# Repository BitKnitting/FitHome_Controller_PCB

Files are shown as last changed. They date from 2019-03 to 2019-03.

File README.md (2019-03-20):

# Tisham_PCB_Feather
The goal of this PCB is to supply a Feather to provide the CPU and networking.
# SPI
The meter and CPU talk to each other using SPI.  I just can't map SPI between CPUs and their slaves enough times not to get confused by the differing nomenclatures.  Tisham's labeling of SPI used the SI/SO nomenclature on the slave (the meters) and MOSI/MISO on the master (the CPU).  This maps to:  
SPI mapping  

## CS Pins

I plan to support Feather LoRa and Huzzah.  This way, I can do either RFM95 or wifi.  
### Huzzah
Previously, I used pins 0 and 15 for the two CS pins.  Here is the pinout diagram for the Huzzah:  
Huzzah pinout diagram  

The "0" and "15" refer to how the IDE (Arduino, CP) identify the pin.  The "physical pin" for 0 is 12 and for 15 is 10.  Because all of this confuses me quickly, I can best find these by noting:  
* one CS pin - I'll id as CS 0 -  is 5 pins up on the right.  This is pin 0(IDE)/12(physical).
* one CS pin is 6 pins up on the right.  This is pin 15(IDE)/10(physical).
__Tested both.  I could set pin values to HIGH (3.3) and LOW (0.0).__  
### LoRa
Here is the pinout diagram for the LoRa:  
LoRa pinout diagram

* The pin 5 pins up on the right is 9 (IDE) / 12 (physical)   Hopefully this can also be CS 0 
* The pin 6 pins up on the right is 10 (IDE) / 27 (physical). 
__Tested both.  I could set pin values to HIGH (3.3) and LOW (0.0).__
## 3V3 In

# Circuit Python
I keep getting different Feathers that need CP installed.  Steps to install:  
* [Download the right version of CP from here](https://github.com/adafruit/circuitpython/releases/latest).  
## Huzzah
I'm conflicted if the Huzzah if Adafruit has dropped support for the Huzzah.  The .bin is included in the latest releases.  So I'm using that.
You'll need the [ampy](https://learn.adafruit.com/micropython-basics-load-files-and-run-code/install-ampy) and [esptool](https://pypi.org/project/esptool/) tools installed.
* First thing to do is erase the flash on the ESP826.  I like to start by naming the port, then erasing.
```
$ export PORT=/dev/tty.SLAB_USBtoUART
$ esptool.py -p $PORT erase_flash
```
* Jumper GPIO0 and GND so the ESP826 is in boot mode.
* Write the bin you downloaded (I renamed my cphuzzah.bin)  
```
esptool.py -p /dev/cu.SLAB_USBtoUART write_flash --flash_size=detect 0 cphuzzah.bin
```
* Remove the jumper wire and hit the restart button.

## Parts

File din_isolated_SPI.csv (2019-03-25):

Reference | Value | Footprint | Datasheet | Availability | Description | MP | PN | Package | Price | manf# | DNP
U1 | SI8661AB-B-IS1 | Housings_SOIC:SOIC-16_3.9x9.9mm_Pitch1.27mm | Silicon Labs | Warning | General Purpose tal Isolator 2500Vrms 6 Channel 1Mbps 35kV/µs CMTI 16-SOIC (0.154 , 3.90mm Width) | SI8661AB-B-IS1 | SI8661AB-B-IS1 | SOIC-16 Silicon Labs | 2.12 USD | SI8661AB-B-IS1
J1 | CONN_01X10 | Connectors_Molex:Molex_MicroLatch-53253-1070_10x2.00mm_Straight |  |  |  |  | 53290-1080 |  |  | 53290-1080
C1 | .1u | Capacitor_SMD:C_0805_2012Metric |  |  |  |  | C |  |  | 0201ZD104KAT2A
C2 | .1u | Capacitor_SMD:C_0805_2012Metric |  |  |  |  | C
R1 | 47 | Resistor_SMD:R_0805_2012Metric |  |  |  |  | R |  |  | CRCW060347R0JNEB
R2 | 47 | Resistor_SMD:R_0805_2012Metric |  |  |  |  | R
R3 | 47 | Resistor_SMD:R_0805_2012Metric |  |  |  |  | R
R4 | 47 | Resistor_SMD:R_0805_2012Metric |  |  |  |  | R
R6 | 47 | Resistor_SMD:R_0805_2012Metric |  |  |  |  | R
R7 | 47 | Resistor_SMD:R_0805_2012Metric |  |  |  |  | R
R8 | 47 | Resistor_SMD:R_0805_2012Metric |  |  |  |  | R
R9 | 47 | Resistor_SMD:R_0805_2012Metric |  |  |  |  | R
R10 | 47 | Resistor_SMD:R_0805_2012Metric |  |  |  |  | R
R12 | 47 | Resistor_SMD:R_0805_2012Metric |  |  |  |  | R
G1 | LOGO | Whatnick_logo:Whatnick_logo |  |  |  |  | X
MS1 | ADAFRUIT_FEATHERWING_FitHome | HappyDayEnergyMonitor:ADAFRUIT_FEATHER |  |  |  |  | X

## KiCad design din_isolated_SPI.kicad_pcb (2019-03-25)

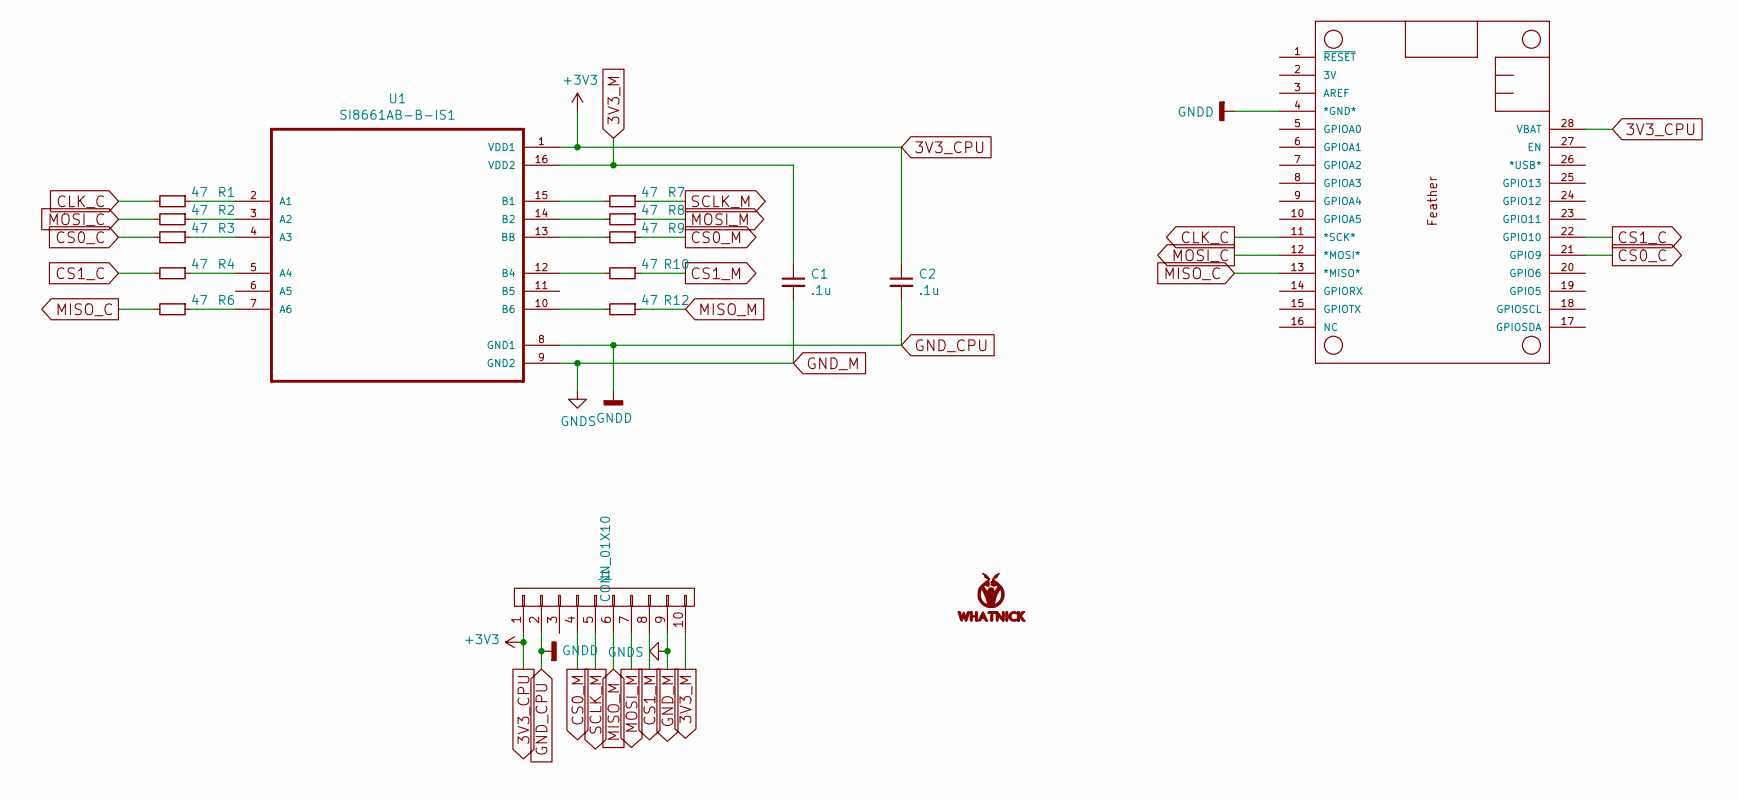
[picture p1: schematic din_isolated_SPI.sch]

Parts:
C1, C2: .1u; C_0805_2012Metric
G1: LOGO; Whatnick_logo
J1: CONN_01X10; Molex_MicroLatch-53253-1070_10x2.00mm_Straight
MS1: ADAFRUIT_FEATHERWING_FitHome; ADAFRUIT_FEATHER
R1, R2, R3, R4, R6, R7, R8, R9, R10, R12: 47; R_0805_2012Metric
U1: SI8661AB-B-IS1; SOIC-16_3.9x9.9mm_Pitch1.27mm

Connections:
3V3_CPU: C2.1, J1.1, MS1.28 (VBAT), U1.1 (VDD1)
3V3_M: C1.1, J1.10, U1.16 (VDD2)
CLK_C: MS1.11 (*SCK*), R1.2
CS0_C: MS1.21 (GPIO9), R3.2
CS0_M: J1.4, R9.1
CS1_C: MS1.22 (GPIO10), R4.2
CS1_M: J1.8, R10.1
GND_CPU: C2.2, J1.2, MS1.4 (*GND*), U1.8 (GND1)
GND_M: C1.2, J1.9, U1.9 (GND2)
MISO_C: MS1.13 (*MISO*), R6.2
MISO_M: J1.6, R12.1
MOSI_C: MS1.12 (*MOSI*), R2.2
MOSI_M: J1.7, R8.1
unnamed: R1.1, U1.2 (A1)
unnamed: R2.1, U1.3 (A2)
unnamed: R3.1, U1.4 (A3)
unnamed: R4.1, U1.5 (A4)
unnamed: R6.1, U1.7 (A6)
unnamed: R7.2, U1.15 (B1)
unnamed: R8.2, U1.14 (B2)
unnamed: R9.2, U1.13 (BB)
unnamed: R10.2, U1.12 (B4)
unnamed: R12.2, U1.10 (B6)
SCLK_M: J1.5, R7.1

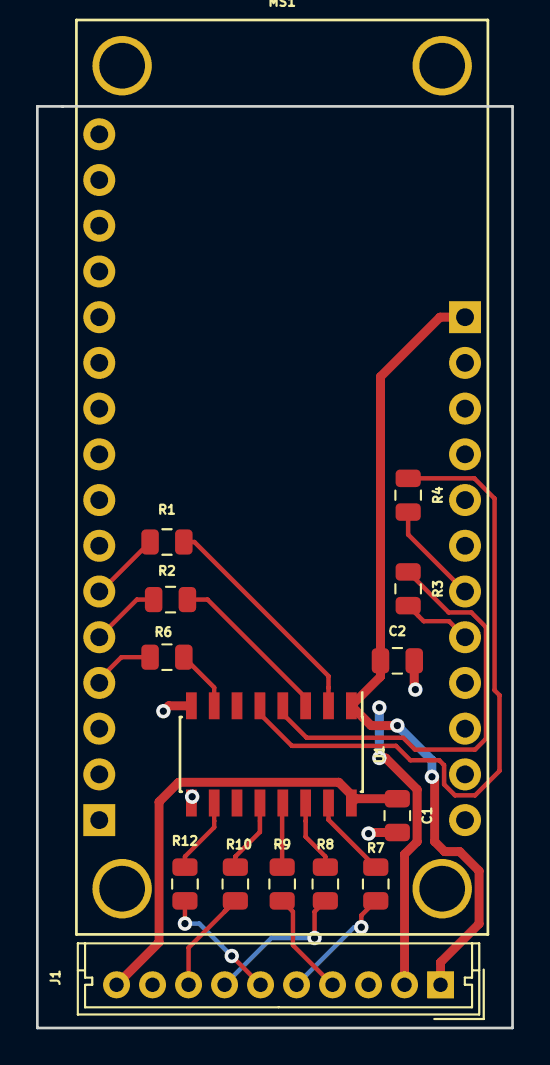
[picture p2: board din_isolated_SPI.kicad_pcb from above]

Board: 2 copper layers, 26.4 x 51.2 mm, 16 parts (0 on the bottom side), 24 nets.

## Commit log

2019-03-19 updating readme and schematic.
    [din_isolated_SPI.sch]
2019-03-20 First pass at evolution of Tisham's board.
    [din_isolated_SPI.sch]
2019-03-25 PCB submitted to OSH Park. BoM created.
    [din_isolated_SPI.csv, din_isolated_SPI.kicad_pcb, din_isolated_SPI.sch]
